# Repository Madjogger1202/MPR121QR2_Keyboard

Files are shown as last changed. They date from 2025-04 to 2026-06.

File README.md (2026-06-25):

# MPR121QR2_Keyboard

**Мини-клавиатура на 12 сенсорных кнопок: ёмкостный драйвер MPR121QR2, контроллер RP2040 и цветной дисплей ST7735.**

Компактная плата сенсорной клавиатуры на базе контроллера касаний **MPR121QR2** (NXP), обслуживающего 12 ёмкостных кнопок по I²C. Логику и обработку берёт на себя **RP2040**, для индикации установлен дисплей **0.96" ST7735**, а на борту есть узел измерения тока. Завершающая плата небольшой серии проектов на RP2040.

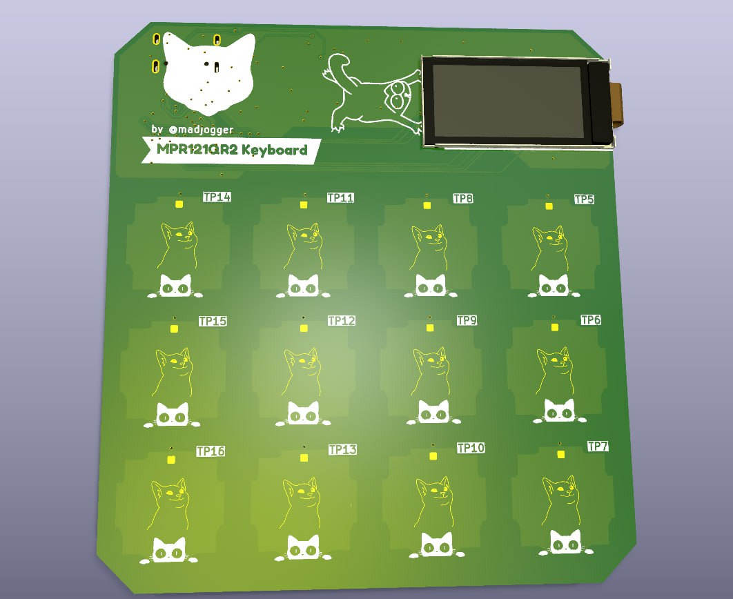
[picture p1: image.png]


## Обзор

- **Название проекта:** MPR121QR2_Keyboard
- **Контроллер касаний:** NXP MPR121QR2 — 12-канальный ёмкостный сенсор (I²C)
- **Микроконтроллер:** Raspberry Pi RP2040 (двухъядерный Cortex-M0+)
- **Дисплей:** 0.96" ST7735 (цветной TFT, SPI)
- **Доп. функция:** измерение тока на плате
- **Назначение:** сенсорная клавиатура / ввод касанием, эксперименты с ёмкостными кнопками

## Ключевые особенности

- **12 ёмкостных кнопок** — MPR121QR2 обслуживает до 12 сенсорных электродов с автоконфигурацией и настраиваемыми порогами
- **I²C-интерфейс + IRQ** — компактное подключение, прерывание по событию касания
- **RP2040** — двухъядерный Arm Cortex-M0+ до 133 МГц, обработка касаний и вывод на дисплей
- **Цветной дисплей 0.96" ST7735** — индикация состояния кнопок и данных по SPI
- **Измерение тока** — узел контроля потребления на плате
- **Доступная элементная база** — MPR121 широко доступен, готовый модуль с ним стоит около 100 руб, так что решение легко повторить

## Что на плате

| Блок | Компонент | Назначение |
|---|---|---|
| Контроллер касаний | MPR121QR2 | 12 ёмкостных кнопок по I²C |
| Микроконтроллер | RP2040 | Обработка касаний, логика, вывод на дисплей |
| Дисплей | 0.96" ST7735 | Цветной TFT-индикатор (SPI) |
| Измерение тока | узел токового контроля | Замер потребления |
| Интерфейс | USB | Питание и связь с хостом |

## Технические характеристики

| Параметр | Значение |
|---|---|
| Контроллер касаний | NXP MPR121QR2, 12 электродов |
| Интерфейс сенсора | I²C (до 400 кГц) + линия IRQ |
| Микроконтроллер | RP2040, 2× Cortex-M0+ до 133 МГц |
| Дисплей | 0.96" ST7735, цветной TFT, SPI |
| Измерение тока | встроенный узел |
| Питание | USB / 3.3 В |

## Применение

- Сенсорная клавиатура / панель ввода касанием
- Изучение ёмкостных кнопок и контроллера MPR121
- Компактный пользовательский интерфейс с индикацией на дисплее
- Учебная/макетная плата на RP2040

## Среда разработки

- **Схема и плата:** KiCad
- **Прошивка:** PlatformIO / Arduino / Pico SDK (RP2040)
- **Документация на компоненты:** datasheet MPR121 (NXP), RP2040 (Raspberry Pi), ST7735

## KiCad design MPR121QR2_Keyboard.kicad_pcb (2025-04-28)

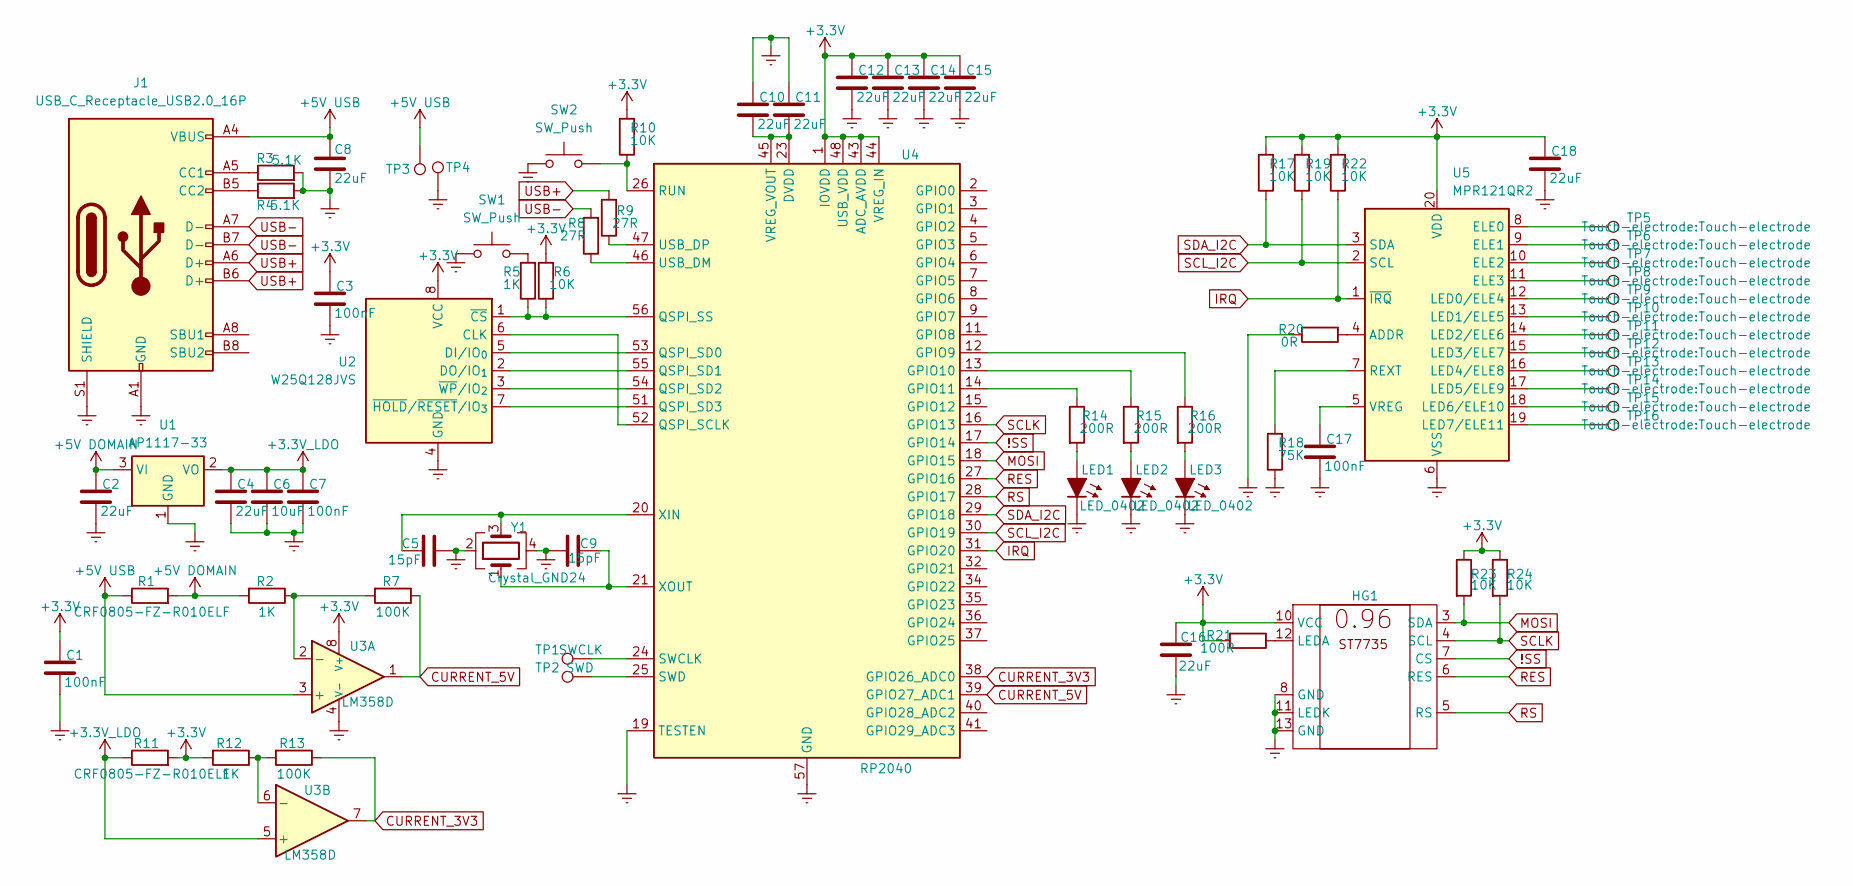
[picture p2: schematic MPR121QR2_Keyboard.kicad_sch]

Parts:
C1, C3, C7, C17: 100nF; C_0402_1005Metric
C2, C4, C8, C10, C11, C12, C13, C14, C15, C16, C18: 22uF; C_0402_1005Metric
C5, C9: 15pF; C_0402_1005Metric
C6: 10uF; C_0402_1005Metric
HG1: ST7735 0.96
J1: USB_C_Receptacle_USB2.0_16P; USB_C_Receptacle_GCT_USB4105-xx-A_16P_TopMnt_Horizontal
LED1, LED2, LED3: LED_0402; LED_0402_1005Metric
R1: CRF0805-FZ-R010ELF; R_0805_2012Metric_Pad1.15x1.40mm
R2, R5, R12: 1K; R_0402_1005Metric
R3, R4: 5.1K; R_0402_1005Metric
R6, R10, R17, R19, R22, R23, R24: 10K; R_0402_1005Metric
R7, R13: 100K; R_0402_1005Metric
R8, R9: 27R; R_0402_1005Metric
R11: CRF0805-FZ-R010ELF; R_0805_2012Metric
R14, R15, R16: 200R; R_0402_1005Metric
R18: 75K; R_0402_1005Metric
R20: 0R; R_0402_1005Metric
R21: 100R; R_0402_1005Metric
SW1, SW2: SW_Push; SW_SPST_B3U-1000P
TP1: SWCLK; TestPoint_Pad_D1.0mm
TP2: SWD; TestPoint_Pad_D1.0mm
TP3, TP4: TestPoint_Pad_1.5x1.5mm
TP5, TP6, TP7, TP8, TP9, TP10, TP11, TP12, TP13, TP14, TP15, TP16: TestPoint; Touch-electrode
U1: AP1117-33; SOT-223-3_TabPin2
U2: W25Q128JVS; SOIC-8_5.3x5.3mm_P1.27mm
U3: LM358D; SO-8_3.9x4.9mm_P1.27mm
U4: RP2040; QFN-56-1EP_7x7mm_P0.4mm_EP3.2x3.2mm
U5: MPR121QR2; UQFN-20_3x3mm_P0.4mm
Y1: Crystal_GND24; Crystal_SMD_Abracon_ABM8G-4Pin_3.2x2.5mm

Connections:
!SS: HG1.7 (CS), U4.17 (GPIO14)
+3.3V: C1.1, C3.1, C12.1, C13.1, C14.1, C15.1, C16.1, C18.1, HG1.10 (VCC), R6.2, R10.2, R11.2, R12.2, R17.2, R19.2, R21.2, R22.2, R23.1, R24.1, U2.8 (VCC), U3.8 (V+), U4.1 (IOVDD), U4.10 (IOVDD), U4.22 (IOVDD), U4.33 (IOVDD), U4.42 (IOVDD), U4.43 (ADC_AVDD), U4.44 (VREG_IN), U4.48 (USB_VDD), U4.49 (IOVDD), U5.20 (VDD)
+3.3V_LDO: C4.1, C6.1, C7.1, R11.1, U1.2 (VO), U3.5 (+)
+5V DOMAIN: C2.1, R1.2, R2.2, U1.3 (VI)
+5V USB: C8.1, J1.A4 (VBUS), J1.A9 (VBUS), J1.B4 (VBUS), J1.B9 (VBUS), R1.1, TP3.1, U3.3 (+); also elsewhere on the board
CURRENT_3V3: R13.1, U3.7, U4.38 (GPIO26_ADC0)
CURRENT_5V: R7.1, U3.1, U4.39 (GPIO27_ADC1)
Earth: C1.2, C2.2, C3.2, C4.2, C5.2, C6.2, C7.2, C8.2, C9.1, C10.1, C11.1, C12.2, C13.2, C14.2, C15.2, C16.2, C17.2, C18.2, HG1.8 (GND), HG1.11 (LEDK), HG1.13 (GND), J1.A1 (GND), J1.A12 (GND), J1.B1 (GND), J1.B12 (GND), J1.S1 (SHIELD), LED1.1 (K), LED2.1 (K), LED3.1 (K), R3.2, R4.2, R18.1, R20.2, SW1.1, SW2.1, TP4.1, U1.1 (GND), U2.4 (GND), U3.4 (V-), U4.19 (TESTEN), U4.57 (GND), U5.6 (VSS), Y1.2, Y1.4; also elsewhere on the board
IRQ: R22.1, U4.31 (GPIO20), U5.1 (~IRQ)
MOSI: HG1.3 (SDA), R23.2, U4.18 (GPIO15)
unnamed: HG1.12 (LEDA), R21.1
unnamed: J1.A5 (CC1), R3.1
unnamed: J1.B5 (CC2), R4.1
unnamed: LED1.2 (A), R14.2
unnamed: LED2.2 (A), R15.2
unnamed: LED3.2 (A), R16.2
unnamed 16: R5.2, SW1.2; also elsewhere on the board
unnamed: U2.6 (CLK), U4.52 (QSPI_SCLK)
unnamed: U2.5 (DI/IO_{0}), U4.53 (QSPI_SD0)
unnamed: U2.2 (DO/IO_{1}), U4.55 (QSPI_SD1)
unnamed: R5.1, R6.1, U2.1 (~CS), U4.56 (QSPI_SS)
unnamed: U2.7 (~HOLD/~RESET/IO_{3}), U4.51 (QSPI_SD3)
unnamed: U2.3 (~WP/IO_{2}), U4.54 (QSPI_SD2)
unnamed: R2.1, R7.2, U3.2 (-)
unnamed: R12.1, R13.2, U3.6 (-)
unnamed: R16.1, U4.12 (GPIO9)
unnamed: R15.1, U4.13 (GPIO10)
unnamed: R14.1, U4.14 (GPIO11)
unnamed 28: R10.1, SW2.2, U4.26 (RUN); also elsewhere on the board
unnamed 29: TP1.1, U4.24 (SWCLK); also elsewhere on the board
unnamed 30: TP2.1, U4.25 (SWD); also elsewhere on the board
unnamed: R8.1, U4.46 (USB_DM)
unnamed: R9.1, U4.47 (USB_DP)
unnamed: C10.2, C11.2, U4.23 (DVDD), U4.45 (VREG_VOUT), U4.50 (DVDD)
unnamed: C5.1, U4.20 (XIN), Y1.3
unnamed: C9.2, U4.21 (XOUT), Y1.1
unnamed: R20.1, U5.4 (ADDR)
unnamed: TP5.1, U5.8 (ELE0)
unnamed: TP6.1, U5.9 (ELE1)
unnamed: TP7.1, U5.10 (ELE2)
unnamed: TP8.1, U5.11 (ELE3)
unnamed: TP9.1, U5.12 (LED0/ELE4)
unnamed: TP10.1, U5.13 (LED1/ELE5)
unnamed: TP11.1, U5.14 (LED2/ELE6)
unnamed: TP12.1, U5.15 (LED3/ELE7)
unnamed: TP13.1, U5.16 (LED4/ELE8)
unnamed: TP14.1, U5.17 (LED5/ELE9)
unnamed: TP15.1, U5.18 (LED6/ELE10)
unnamed: TP16.1, U5.19 (LED7/ELE11)
unnamed: R18.2, U5.7 (REXT)
unnamed: C17.1, U5.5 (VREG)
RES: HG1.6 (RES), U4.27 (GPIO16)
RS: HG1.5 (RS), U4.28 (GPIO17)
SCLK: HG1.4 (SCL), R24.2, U4.16 (GPIO13)
SCL_I2C: R19.1, U4.30 (GPIO19), U5.2 (SCL)
SDA_I2C: R17.1, U4.29 (GPIO18), U5.3 (SDA)
USB+: J1.A6 (D+), J1.B6 (D+), R9.2
USB-: J1.A7 (D-), J1.B7 (D-), R8.2

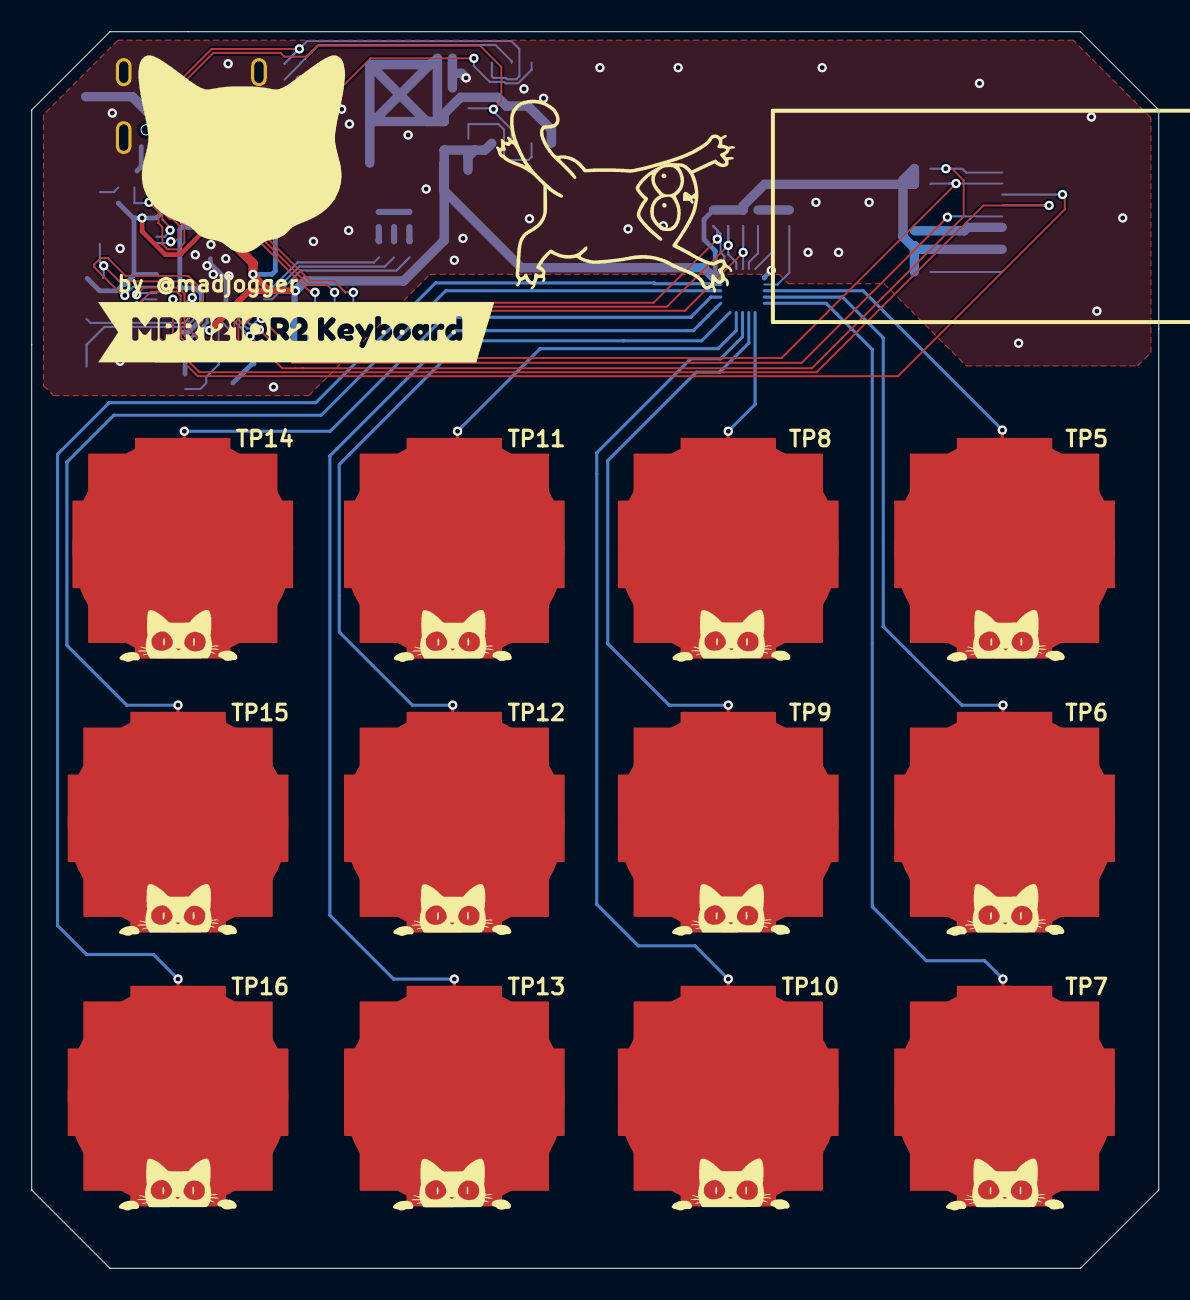
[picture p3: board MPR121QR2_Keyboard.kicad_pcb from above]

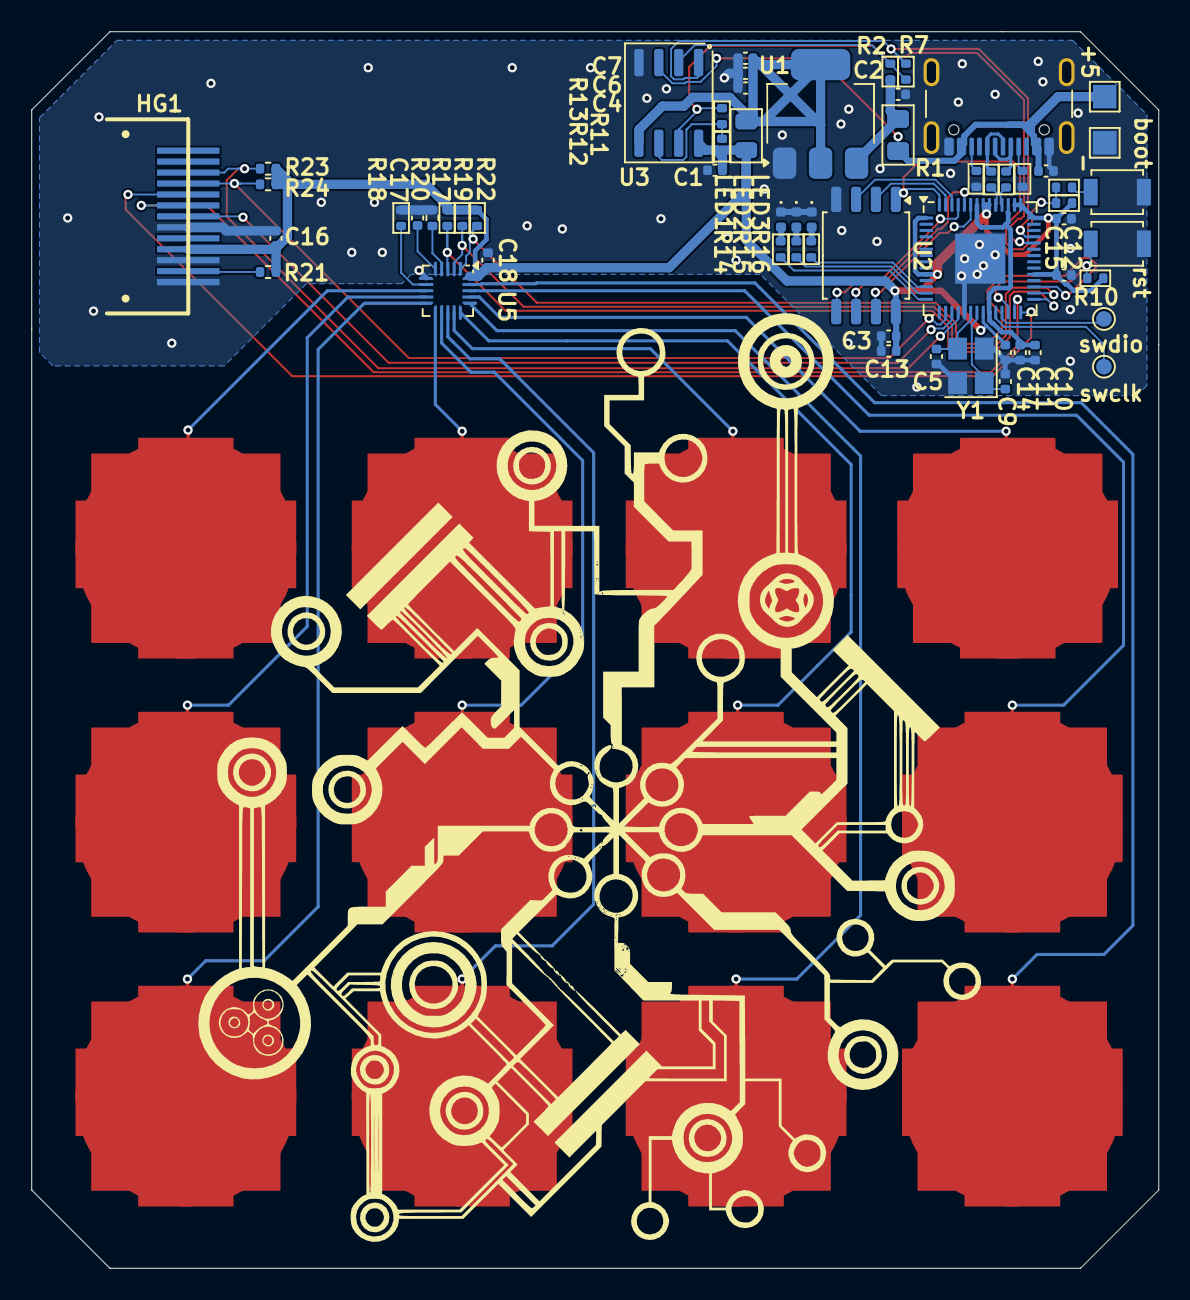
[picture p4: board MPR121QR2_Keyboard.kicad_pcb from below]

Board: 2 copper layers, 72.0 x 79.0 mm, 72 parts (59 on the bottom side), 58 nets.

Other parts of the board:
+5: TestPoint_Pad_1.5x1.5mm
-: TestPoint_Pad_1.5x1.5mm
boot: SW_Push; SW_SPST_B3U-1000P
kibuzzard-680FD2EB: G***; kibuzzard-680FD2EB
rst: SW_Push; SW_SPST_B3U-1000P
swclk: SWCLK; TestPoint_Pad_D1.0mm
swdio: SWD; TestPoint_Pad_D1.0mm

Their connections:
+5V USB: +5.1; also elsewhere on the board
Earth: -.1, boot.1, rst.1; also elsewhere on the board
unnamed 16: boot.2; also elsewhere on the board
unnamed 28: rst.2; also elsewhere on the board
unnamed 29: swclk.1; also elsewhere on the board
unnamed 30: swdio.1; also elsewhere on the board
